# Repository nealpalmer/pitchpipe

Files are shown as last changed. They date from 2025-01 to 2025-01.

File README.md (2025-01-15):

# pitchpipe
DIY electronic pitchpipe

A work in progress, and not everything is working yet - Jan 2025.

This is a design for a small electronic pitchpipe.
Features:
- 3W speaker with 3W amplifier - it should be loud enough to be heard across a fairly large chorus
- 12 buttons for the 12 pitches
- white buttons for the 7 pitches, with 1 led for each.
- black buttons for the 5 #/b pitches
- 2 side buttons for repeat last note, sustain, "shift"
- 1 3-position switch for volume control (chorus loud, quartet, quiet so that the director can't hear you playing a pitch)
- built in rechargeable battery with about 4hours of runtime (i.e. 4 hours of continuously playing a pitch) - at least the basic math shows it running that long
- USB-C 0.5A and 1A charging (not sure when to select which, and probably ends up being a compile option only), 2 or 4 hour charge time
- Can charge and run at the same time (at a reduced charging rate)
- Can possibly set the output frequency to be exactly the right pitch (better than 0.1cents=100ppm of the oscillator).
- It is possible to set the range of the pitches (i.e. C4-B4 or F4-E5).
- You can use your imagination to set more features using the side buttons to choose some new set of features.
- Pressing the "shift" side button will light up the 7leds for a few seconds, so you can see what pitch you are about to play while on a dark stage.

This git repository contains:
- circuit board with schematic and PCB layout (order from oshpark for about $20 for 3 copies).
- enclosure to be 3d printed out of ABS or PETG - openscad & .STL & bambu
- C Source code for the pic microcontroller
- C Source code for the esp32c5 ARM processor (wifi and bluetooth not used)
- C Source code for windows command line application to program the pic microcontroller through USB
- instructions for compiling and programming all 3 applications using free compilers (Arduino, MPLAB, gcc/cygwin)

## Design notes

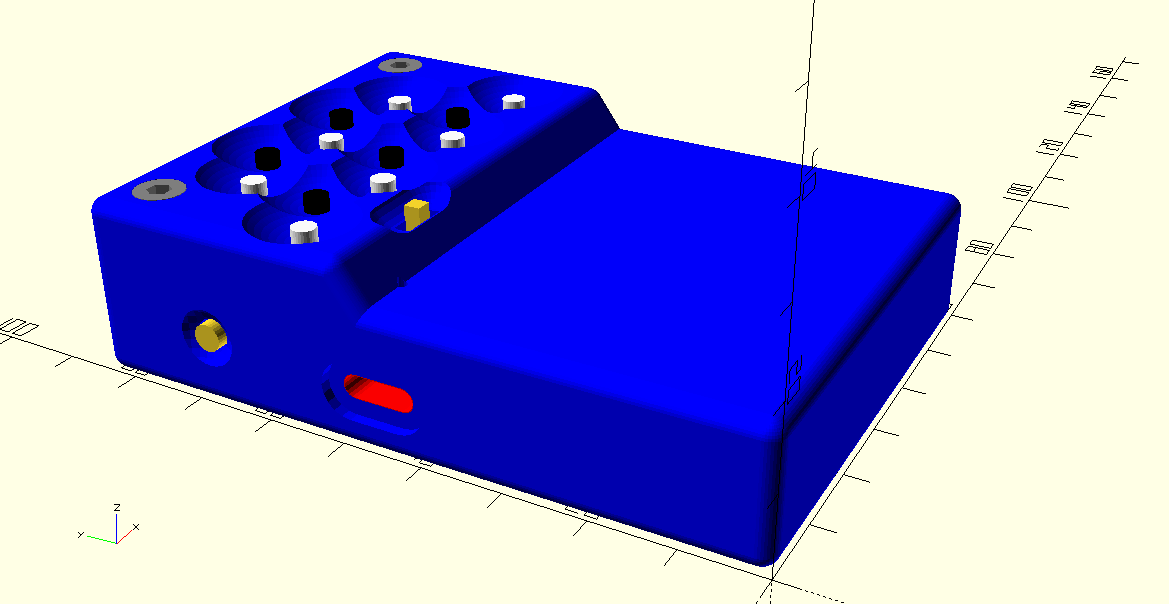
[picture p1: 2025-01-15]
pitchpipe_model.png

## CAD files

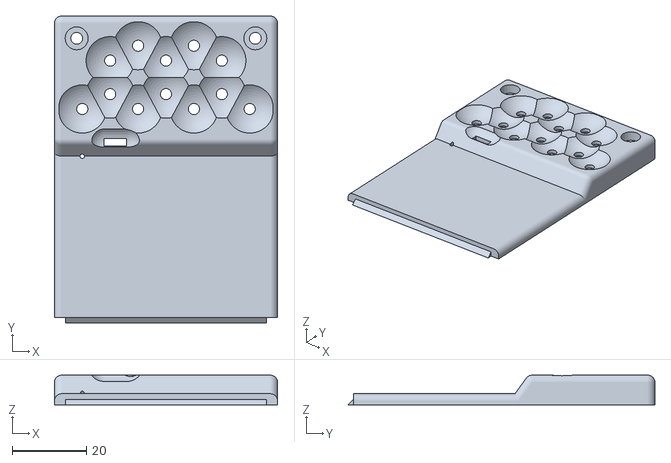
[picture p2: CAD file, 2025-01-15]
enclosure/pitchpipe_lid.stl
60.0 x 82.5 x 7.99

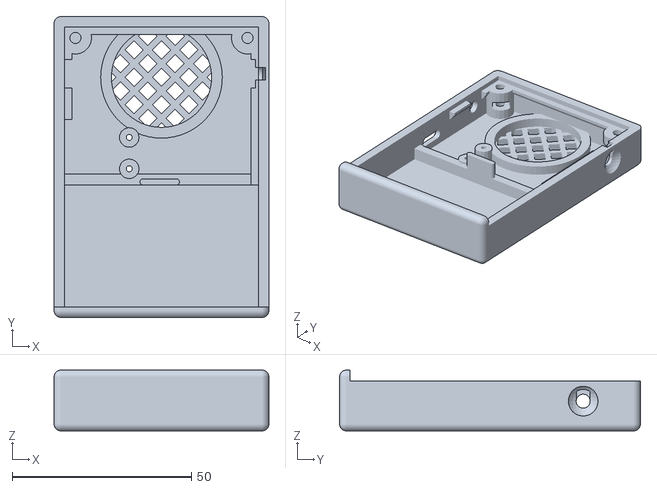
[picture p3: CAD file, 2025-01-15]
enclosure/pitchpipe_base.stl
60.0 x 84.0 x 17.0

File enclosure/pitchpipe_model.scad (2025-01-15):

VERSION = "r1";
// Version 1:
// Cons:
// - Didn't have the version number in the plastic.
// - Lid doesn't fit completely flush.  Need to subtract 0.1mm from the battery end of the lid and base.
// - Side button indents seem to have too small of a sphere radius.  Need to see how hard it is to press the buttons.
// - Took 1hr5min to print
// - Between base and lid has an apparent gap.  I should probably add a feature to fix:  2 more screws?  top/bottom clips?  Battery slide in cover+ screw down button cover?
// - M3 screws into plastic will need a smaller hole than 3.0mm.  Haven't tried the insertable nuts yet (might not bother).
// - volume switch seems VERY small
// - forgot to put holes in the lid for the leds.
// Pros:
// - Feels small in my hand.
// - Top button holes feel pretty good.
// - 15% gyroid, 2 wall shells, 3 bottom&top solid makes a pretty sturdy case out of PLA.
// - good print, no mess, no apparent overhang issues
// - M3 screws sit pretty flush.


INCH = 25.4;

WALL = 3;

SPKR_D = 1.1*INCH;
SPKR_D2 = 0.5*INCH;
SPKR_H = 6;

SCREW_D = 3;
SCREW_LEN = 18;
SCREW_HEAD_D = 6;
SCREW_HEAD_H = 3;
NUT_Z = WALL+WALL;
NUT_W = 5.5;
NUT_H = 2.4;

BUTTON_H = 7;
BUTTON_D = 3;
BUTTON_W = 5;
BUTTON_SIDE_Y = 31;
BUTTON_SIDE_Z = 4.1;
BUTTON_SIDE_D = 3.4;
BUTTON_SIDE_LEN = (5.85-2.5-0.35); // should be 3mm
BUTTON_SIDE_W = 7;
BUTTON_SIDE_L = 8;
BUTTON_SIDE_H = 7.5;

//BATT_W = 36;
//BATT_L = 60;
//BATT_H = 7;
BATT_L = 34; // amazon 103450 battery
BATT_W = 50;
BATT_H = 10;

ESP_W = 0.7*INCH;
ESP_L = 0.7*INCH;
ESP_H = 0.062*INCH+0.1*INCH;
USB_L = 9;
USB_H = 3;
USB_STICK_OUT = 1.7; // need to re-measure me.
USB_Y = 0;
USB_Z = 0;
USB_CONN_W = 8.3+0.7;
USB_CONN_H = 2.65+0.35;
USB_CABLE_W = 12.2+0.8;
USB_CABLE_H = 6.3+0.7;
ESP_BUTTONS_D = 1.5;
ESP_BUTTONS_XY = [
	[18,4.5],
	[18,13.25]
];

PIC_W = 7.8;
PIC_L = 7.2;
PIC_H = 2.0;

PCB_W = 54;
PCB_L = 44;
PCB_H = 0.062*INCH;

LEDGE_W = 2;
LEDGE_TOP = 1;
LEDGE_H = 3;

SWITCH_W = 12.6; // OS103011
SWITCH_L = 4.3;
SWITCH_H = 4.0;
SWITCH_H2 = 4+4;
SWITCH_TRAVEL = 6;
SWITCH_X = 13.462;
SWITCH_Y = 13.208;

MCLR_W = 1.7+0.2;
MCLR_L = 2.5+0.2;
MCLR_H = 1;
MCLR_X = 4.5;
MCLR_Y = 9.3;
MCLR_D = 1;

CORNER_QUALITY = 40;

ESP_BUTTONS_H = PCB_H+0.1+PCB_H+1.5;

W = WALL+PCB_W+WALL;
L = PCB_L+WALL+WALL+BATT_L;
H = WALL+(BATT_H+1)+(BUTTON_H+1); // 22mm thick
SPLIT = H-8; // where the base and lid split apart
CORNER_R = 2;

SPKR_X = W/2;
SPKR_Y = L-WALL-SPKR_D/2;

screws_xy = [
	//[6,6],
	//[W-6,6],
	//[WALL+SCREW_D/2,L-(WALL+SCREW_D/2)],
	//[W-(WALL+SCREW_D/2),L-(WALL+SCREW_D/2)]
	[WALL+3,L-(WALL+3)],
	[W-(WALL+3),L-(WALL+3)]
];

buttons = [
	[12+0*7.5,PCB_L-9,"white",90],   // 12,   35
	[12+1*7.5,PCB_L-9+4,"black",0], // 19.5, 39
	[12+2*7.5,PCB_L-9,"white",90],   // 27,   35
	[12+3*7.5,PCB_L-9+4,"black",0], // 34.5, 39
	[12+4*7.5,PCB_L-9,"white",90],   // 42,   35

	[4.5+0*7.5,PCB_L-22,"white",90],   // 4.5,  22
	[4.5+1*7.5,PCB_L-22+4,"black",0], // 12,   26
	[4.5+2*7.5,PCB_L-22,"white",90],   // 19.5, 22
	[4.5+3*7.5,PCB_L-22+4,"black",0], // 27,   26
	[4.5+4*7.5,PCB_L-22,"white",90],   // 34.5, 22
	[4.5+5*7.5,PCB_L-22+4,"black",0], // 42,   26
	[4.5+6*7.5,PCB_L-22,"white",90],   // 49.5, 22
];
BUTTON_DEPRESSION_R = 17;

// outside of the box
module box(is_lid) {
 // color("gray")
//intersection() {
 //cube([W+1,L+1,SPLIT])

difference() {
 if (0) 
		// square corners everywhere
 	cube([W,L,H /*(is_lid ? H : SPLIT)*/]);
 else {
		// rounded corners for bottom 7/8th
	hull() {
		for (x=[CORNER_R,W-CORNER_R], y=[CORNER_R,L-CORNER_R], z=[CORNER_R,SPLIT+WALL-CORNER_R])
			translate([x,y,z])
				sphere(r=CORNER_R,$fn=CORNER_QUALITY);
	}
		// rounded corners for top  1/8th
	hull() {
		for (x=[CORNER_R,W-CORNER_R], y=[1+WALL+BATT_L+0,L-CORNER_R], z=[CORNER_R])
			translate([x,y,z])
				sphere(r=CORNER_R,$fn=CORNER_QUALITY);
		for (x=[CORNER_R,W-CORNER_R], y=[1+WALL+BATT_L+13,L-CORNER_R], z=[H-CORNER_R])
			translate([x,y,z])
				sphere(r=CORNER_R,$fn=CORNER_QUALITY);
	}
 	//cube([W,L,H /*(is_lid ? H : SPLIT)*/]);
 }
	// general top depression
 //translate([3,3,H-3])
 	//cube([W-6,L-6,3+1]);
 if (is_lid) {
	translate([-0.5,-0.5,-0.1])
		cube([W+1,L+1,SPLIT+0.1]);

	difference() {
		translate([-0.5,-0.5,SPLIT-0.01])
			cube([W+1,WALL+0.5,WALL+0.1]);
		hull() {
			translate([WALL,WALL/2,SPLIT])
				cube([W-2*WALL,WALL,0.0001]);
			translate([WALL,WALL,SPLIT+WALL/2])
				cube([W-2*WALL,WALL,0.0001]);
		}
	}
 } else {
	translate([-0.5,WALL,SPLIT])
		cube([W+1,L+1,H]);
		// notch for top to fit into
	hull() {
		translate([WALL,WALL/2,SPLIT])
			cube([W-2*WALL,WALL,0.0001]);
		translate([WALL,WALL,SPLIT+WALL/2])
			cube([W-2*WALL,WALL,0.0001]);
	}
 }

	// depression above battery
 if (0)
 hull() {
 	translate([-1,-1,SPLIT+WALL])
		cube([W+2,1+WALL+BATT_L+10,10]);
 	translate([-1,-1,H])
		cube([W+2,1+WALL+BATT_L+13,10]);
 }

	// general inside hole
 difference() {
 	translate([WALL,WALL,WALL])
 		cube([W-2*WALL,L-2*WALL,SPLIT-WALL+0.01]);

		// screw bosses
	for (xy=screws_xy)
		translate([xy[0],xy[1],0.1])
			cylinder(d=SCREW_D+WALL*2,h=SPLIT-0.1-PCB_H,$fn=20);

		// speaker mount
	difference() {
		translate([SPKR_X,SPKR_Y,WALL-0.01])
			cylinder(d=SPKR_D+WALL*2,h=WALL,$fn=60);
		translate([SPKR_X,SPKR_Y,WALL])
			cylinder(d=SPKR_D,h=WALL,$fn=60);
	}

		// battery compartment
	translate([0.1,WALL+BATT_L,0.1])
		cube([W-0.2,WALL,WALL+4-0.1]);

		// PCB edges
	for (xylr=[ [WALL,WALL+BATT_L+ESP_L+0.5,20,0], [WALL,L-WALL,W-2*WALL,90], [W-WALL,L-WALL,PCB_L,180] ]) {
		translate([xylr[0],xylr[1],SPLIT-PCB_H]) 
		rotate(v=[0,0,-1],a=xylr[3])
		hull() {
			translate([-LEDGE_W,0,-LEDGE_TOP])
				cube([LEDGE_W*2,xylr[2],LEDGE_TOP]);
			translate([-0.0001,0,-LEDGE_H])
				cube([0.0001,xylr[2],LEDGE_TOP]);
		}
	}

		// ESP buttons BOSS
 	for (xy = ESP_BUTTONS_XY) {
		translate([WALL+xy[0],L-WALL-PCB_L+xy[1],0]) {
			cylinder(d=ESP_BUTTONS_D+4,h=SPLIT-PCB_H-ESP_BUTTONS_H,$fn=15);
		}
 	}

		// PCB support near battery
	translate([WALL,WALL+BATT_L+1.7/2,0])
	hull() {
		for (x=[21+1.7/2,32-1.7/2]) translate([x,0,0])
			cylinder(d=1.7,h=SPLIT-PCB_H,$fn=20);
	}
	
		// version text for base
	translate([W/2,WALL+BATT_L+WALL+2,WALL-0.01])
	linear_extrude(0.5)
		text(text=VERSION,size=8);

 }

		// version text for lid
	translate([W/2+7,WALL+BATT_L+WALL+8,SPLIT-0.01])
	scale([-1,1,1])
	linear_extrude(0.3)
		text(text=VERSION,size=8);

	// top buttons cut-outs
 translate([WALL,L-WALL-PCB_L,SPLIT-PCB_H])
 for (xy = buttons)
	translate([xy[0],xy[1],PCB_H])
	rotate(a=xy[3],v=[0,0,1]) {
		hull() 
			button(xy[2],BUTTON_H-3); // the shorter hull() makes it have a nice shaft at the top
		button(xy[2],BUTTON_H);
	}

	// side buttons
 translate([WALL,L-WALL-PCB_L,SPLIT-PCB_H]) {
	translate([0,BUTTON_SIDE_Y,-BUTTON_SIDE_Z]) {
		translate([5.555,0,0]) {
				// hole for button shaft
			rotate(a=-90,v=[0,1,0])
				cylinder(d=BUTTON_SIDE_D+0.5, h=BUTTON_SIDE_LEN+10.555, $fn=30);

				// finger indent
			translate([-5.555-WALL-(5-1.5),0,0])
				sphere(r=5,$fn=30);

				// cut for switch body
			translate([-5.555,BUTTON_SIDE_L/-2,-BUTTON_SIDE_H+BUTTON_SIDE_Z+0.01])
				cube([BUTTON_SIDE_W,BUTTON_SIDE_L,BUTTON_SIDE_H]);
		}
		translate([PCB_W-5.555,0,0]) {
				// hole for button shaft
			rotate(a=90,v=[0,1,0])
				cylinder(d=BUTTON_SIDE_D+0.5, h=BUTTON_SIDE_LEN+10.555, $fn=30);

				// finger indent
			translate([5.555+WALL+(5-1.5-0.75),0,0])
				sphere(r=5,$fn=30);

				// cut for switch body
			translate([5.555-BUTTON_SIDE_W-0.75,BUTTON_SIDE_L/-2,-BUTTON_SIDE_H+BUTTON_SIDE_Z+0.01])
				cube([BUTTON_SIDE_W,BUTTON_SIDE_L,BUTTON_SIDE_H]);

				// vertical slot to insert button
			translate([5.555-0.1-3,0,0])
			hull() {
				rotate(a=90,v=[0,1,0])
					cylinder(d=BUTTON_SIDE_D+0.5,h=BUTTON_SIDE_LEN+3-1+0.1,$fn=30);
				translate([0,-(BUTTON_SIDE_D+0*0.5)/2,BUTTON_SIDE_Z+PCB_H-1+0.001])
					//rotate(a=90,v=[0,1,0])
						//cylinder(d=BUTTON_SIDE_D+0.5,h=BUTTON_SIDE_LEN+3-1+0.1,$fn=30);
						cube([BUTTON_SIDE_LEN+3-1+0.1,BUTTON_SIDE_D+0*0.5,1]);
			}
		}
		// do something with BUTTON_SIDE_L cutout in the support ridges
	}
 }

	// MCLRn button
 translate([WALL+MCLR_X,L-WALL-PCB_L+MCLR_Y,SPLIT-0*PCB_H]) {
	cylinder(d=MCLR_D+0.2,h=100,$fn=15);
	cube([MCLR_W,MCLR_L,MCLR_H*2],center=true);

 }

	// ESP buttons access holes
 for (xy = ESP_BUTTONS_XY) {
	translate([WALL+xy[0],L-WALL-PCB_L+xy[1],0]) {
		cylinder(d=ESP_BUTTONS_D+0.2,h=SPLIT,$fn=15);
	}
 }

	// volume switch
	// switch
 translate([WALL,L-WALL-PCB_L,SPLIT]) {
	hull () {
		translate([SWITCH_X-SWITCH_W/2-0.1,SWITCH_Y-SWITCH_L/2-0.1,0])
			cube([SWITCH_W+0.2,SWITCH_L+0.2,SWITCH_H+0.1]);
		translate([SWITCH_X-SWITCH_TRAVEL/2-0.1,SWITCH_Y-2/2-0.1,0])
			cube([SWITCH_TRAVEL,2,SWITCH_H+0.5]);
	}
	translate([SWITCH_X-SWITCH_TRAVEL/2-0.1,SWITCH_Y-2/2-0.1,PCB_H])
		cube([SWITCH_TRAVEL,2,SWITCH_H2]);
		// depression for fingertip
	hull() {
		translate([SWITCH_X-SWITCH_TRAVEL/2,SWITCH_Y,SWITCH_H2+2])
			sphere(r=4,$fn=30);
		translate([SWITCH_X+SWITCH_TRAVEL/2,SWITCH_Y,SWITCH_H2+2])
			sphere(r=4,$fn=30);
	}
	
 }
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
